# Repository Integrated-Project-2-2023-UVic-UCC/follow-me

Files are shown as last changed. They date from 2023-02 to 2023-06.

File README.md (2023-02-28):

# Follow-me robot

Follower robots are devices that use sensors to detect and track a person or object. These robots can be programmed to move in a specific direction and maintain a certain distance from what they are following. Such robots are used in various applications, such as surveillance, logistics, inspection, and support for people with mobility impairments. Thanks to their ability to follow and interact with their users, follower robots are gaining popularity in many fields.

Creating a robot that follows a person and carries boxes can be an exciting and useful project. The robot should be designed with sensors and algorithms that allow it to detect and track the person in real-time, while also being able to carry heavy objects such as boxes. This may require the integration of motors and acceleration mechanisms so that the robot can move efficiently, as well as advanced software that can interpret sensor data to control the robot's movement. With proper planning and the right tools, creating a robot that follows a person and carries boxes could be a highly rewarding task with great potential for practical applications.

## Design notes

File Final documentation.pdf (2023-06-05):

Technical document

# FOLLOW-ME ROBOT

Ferran Huéscar, Eloi Garcia, Jordi Rovira & Jana Bover

## Degree in Mechatronics Engineering

Subject: Integrated Project II

Vic, June of 2023

# Summary

Title:Follow-me robot
Authors: Ferran Huéscar, Eloi Garcia, Jordi Rovira i Jana Bover Subject: Integrated Projects II
Date: Vic, June of 2023
Keywords: Autonomously, Assistance, Sensors, Wireless

The main idea of this project is to create an advanced follow-me robot that can autonomously track and follow a person, providing uninterrupted assistance and support. With the ability to detect and follow individuals using sophisticated sensors, our robot adapts to their movements and pace without the need for constant manual control. This allows users to focus on their primary objectives while the robot autonomously accompanies them in their activities.

In addition to its core tracking capability, the robot will be equipped to carry objects, alleviating the burden on individuals and further optimizing tasks. Whether it's retrieving tools, transporting goods, or providing on-the-go assistance, our robot will be a valuable companion in various professional and personal settings.

Prioritizing convenience and practicality, our follow-me robot will operate wirelessly with a long-lasting battery. This freedom from cables and power outlets ensures maximum flexibility and mobility, enabling the robot to move and follow people in a wide range of environments, including offices, warehouses, and even outdoor spaces.

# Table of Contents

1. Introduction / State of the art – Benchmarking | 6
2. Objectives | 7
3. Development of the project | 9
3.1. Analysis of the problem and possible solutions. | 9
3.2. Description of the design. | 10
3.2.1. Mechanical design | 14
3.2.2. Electrical design. | 16
3.2.3. Control and software. | 18
3.3. Functional testing of the prototype | 19
4. Cost of the project | 20
5. Conclusions | 22
6. Bibliography | 24
7. Annexes | 26

# List of tables

# List of Figures

Figure 1 | First conceptual design of the follow-me robot | 9
Figure 2 | First 3D schematics of the robot with Sketchup | 10
Figure 3 | First 3D schematics of the robot with Sketchup | 11
Figure 4 | X-Ray view of the first 3D schematics | 11
Figure 5 | Render of the main view of the robot | 12
Figure 6 | Render of robot profile view | 13
Figure 7 | Render of robot front view | 13
Figure 8 | Electrical schematics for the connections design | 17

### 1. Introduction / State of the art – Benchmarking

Follower robots have emerged as versatile devices equipped with sensors to detect and track individuals or objects. These intelligent robots can be programmed to navigate specific paths while maintaining a constant distance from their target. Their applications span across diverse fields, including surveillance, logistics, inspection, and assisting people with limited mobility.

As follower robots continue to gain popularity due to their interactive capabilities, there arises an exciting opportunity to design a robot that not only tracks a person in real-time but also assists in carrying heavy objects like boxes. Achieving this requires a combination of cutting-edge sensors, algorithms, motors, acceleration mechanisms, and sophisticated software to interpret sensor data and control the robot's movements efficiently. By undertaking such a project with meticulous planning and the right tools, the creation of a person-following, box-carrying robot can yield substantial rewards and hold immense potential for practical applications.

### 2. Objectives

The main goal of our project is to create an advanced follower robot that can autonomously track and follow a person, providing seamless assistance and support.

But also there are specific objectives of this assignment:

1. Design and build a robot that can follow a person autonomously.
2. Integrate sensors to allow the robot to detect and follow a person.
3. Develop a control system to allow the robot to follow a person smoothly and smoothly.
4. Add additional functionality to the robot, such as the ability to carry objects.
5. Wireless robot using a battery.

Finally, in the management section we aim to structure, follow and organize the following tasks:

| | FEBRUARY | MARCH
TASKS | ASSIGN MENT | 1 4 | 1 5 | 1 6 | 1 7 | 1 8 | 1 9 | 2 0 | 2 1 | 2 2 | 2 3 | 2 4 | 2 5 | 2 6 | 2 7 | 2 8 | 1 | 2 | 3 | 4 | 5 | 6 | 7 | 8 | 9 | 1 0 | 1 1 | 1 2 | 1 3 | 1 4 | 1 5 | 1 6 | 1 7 | 1 8 | 1 9 | 2 0 | 2 1 | 2 2 | 2 3 | 2 4
Milestone 0 document | Group
First design | Ferran
Presentation milestone 0 | Group
Shopping list | Group
Navigation research | Jordi
Motors calculations | Eloi
Electronics research | Jana
Preliminary design | Ferran
Prototipe | Eloi
Hardware test | Jana
Final code | Jordi
Mid-term presentation | Group
Final design | Ferran
GitHub | Group

Table 1. Planning of tasks throughout the project

### 3. Development of the project

Once we discussed the project objectives and what we were willing to achieve, we began searching for possible solutions and subsequently creating initial sketches and diagrams. Below is a detailed explanation of all the solutions obtained and descriptions of the designs: the mechanical design, the electrical design, and all software control. Finally, we present the tests performed until achieving proper functioning.

3.1. Analysis of the problem and possible solutions.

The main problem we aimed to solve was to create a robot that could follow a person or object autonomously, using sensors and control algorithms. After conducting some research, we identified some possible solutions to achieve this goal, which included:

1. Ultrasonic Sensors that can detect obstacles and measure distances using ultrasonic waves. By using these sensors, the robot could follow a person or object without colliding with other obstacles.
2. Infrared Sensors that can detect heat signatures and can be used to detect humans or animals, which would allow the robot to follow a person or pet.
3. Vision-Based Sensors that can detect visual cues, such as colour or shapes, and could be used to track a person or object based on these visual cues.
4. GPS and Navigation so the robot could follow a person or object autonomously without the need for sensors. However, this solution would only work in outdoor environments where GPS signals are available.

After analyzing these solutions, we decided to use a LIDAR. The LIDAR sensors would be used to detect obstacles and p t collisions and to track a person or object.

Additionally, we decided to use two wheels behind to provide the robot with mobility and maneuverability. The robot’s dimensions were 200cm x 150cm, and it weights approximately 1.5kg. The robot is powered by a 12V DC motor and had a battery life of approximately 2 hours.

For the programming part, we used Python, which allow us to control de LIDAR. We also use Arduino to control the motors and other components of the robot.

Overall, the communication of the LIDAR, along with the two wheels drive system, allows to the robot to follow a person or object autonomously while avoiding obstacles.

3.2. Description of the design.

One of the key factors for the successful development of this robot has been the utilization of 3D printing as the primary manufacturing method. 3D printing is a technology that allows the creation of three-dimensional objects by layering materials, providing great versatility in terms of design and production. Thanks to this groundbreaking technique, we have been able to develop a robot with specific features and functionalities tailored for the transportation of small to medium-sized loads.

3D printing has also proven to be a highly efficient method in terms of costs and production times. By avoiding traditional manufacturing processes and associated expenses, we have been able to significantly accelerate the development of our robot, enabling rapid iterations in design and bringing the product to market more efficiently.

Firstly, taking into account the initial specifications, which include two drive wheels, two caster wheels, a platform for weight transportation, and the necessary capacity to accommodate all electronic components, we created the following preliminary layout.

Below is a development of the conceptual design of the robot.

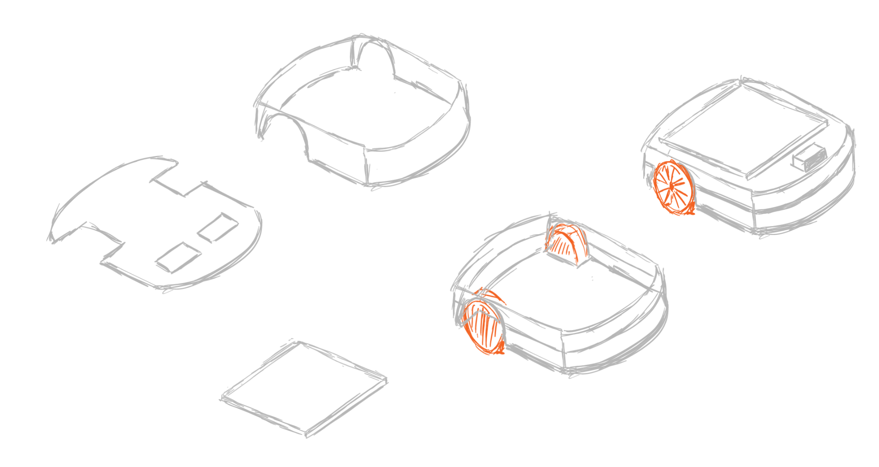
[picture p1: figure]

Fig 1. First conceptual design of the follow-me robot

Once the shape and aesthetics of the robot were determined, we decided to transfer it to the computer to begin deciding on the overall dimensions of the robot.

Therefore, we used the SketchUp program to create the first 3D schematic of our robot. Some changes were made to the second drawing, such as reducing the platform for weight loading since the LIDAR took up a significant portion of the upper platform of the robot. Additionally, we added a groove at the front of the robot. The resulting design is shown below:

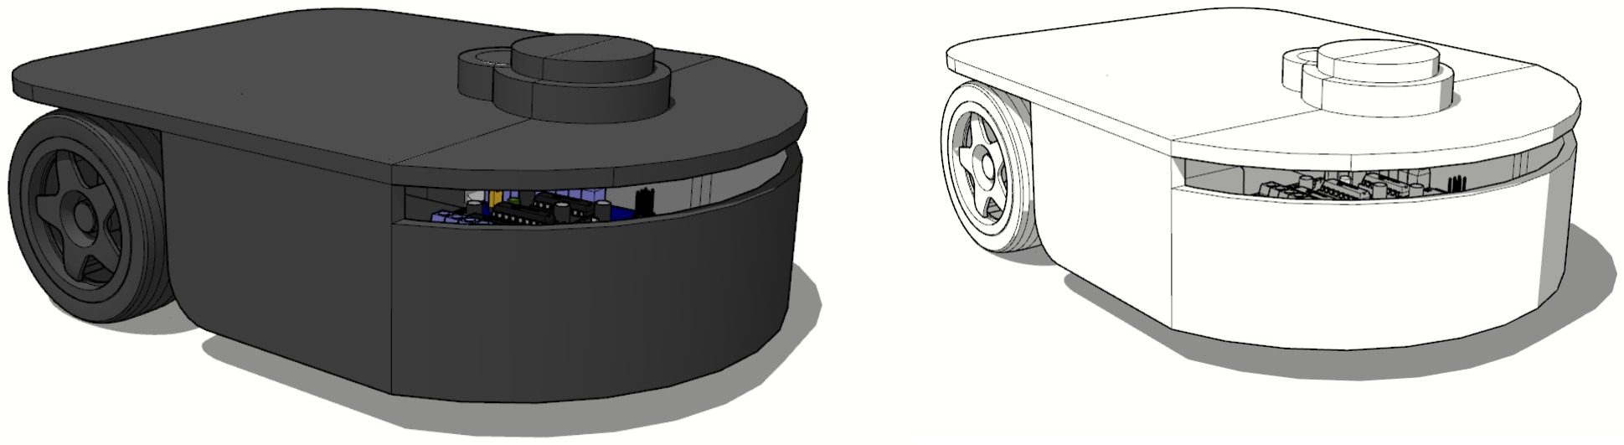
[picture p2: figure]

Fig 2&3. First 3D schematics of the robot with Sketchup

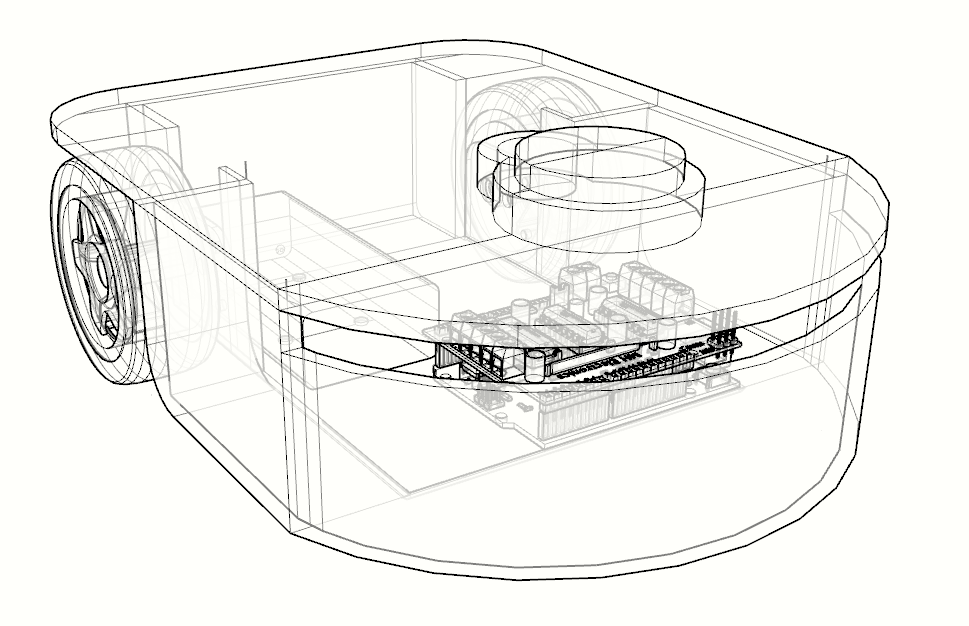
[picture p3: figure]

Fig 4. X-Ray view of the first 3D schematics

Finally, once we have determined the electronic components which motors go, the battery, the drivers, or the diameters of the wheels, we have been able to adapt the design based on the items purchased.

Some of the features that we have implemented in this latest design are supports for the lidar sensor, supports for the connection plate, joints between platforms, or holes to connect the battery externally.

To make the final result in 3D we have used the PTC Creo program since it is easy to use, versatile and all the members of the group can use it without accessibility problems. On the other hand, the final 2D plans have also been made with the same program, which has meant speed when generating them.

Below we show the final renders implemented with the PTC Creo program.

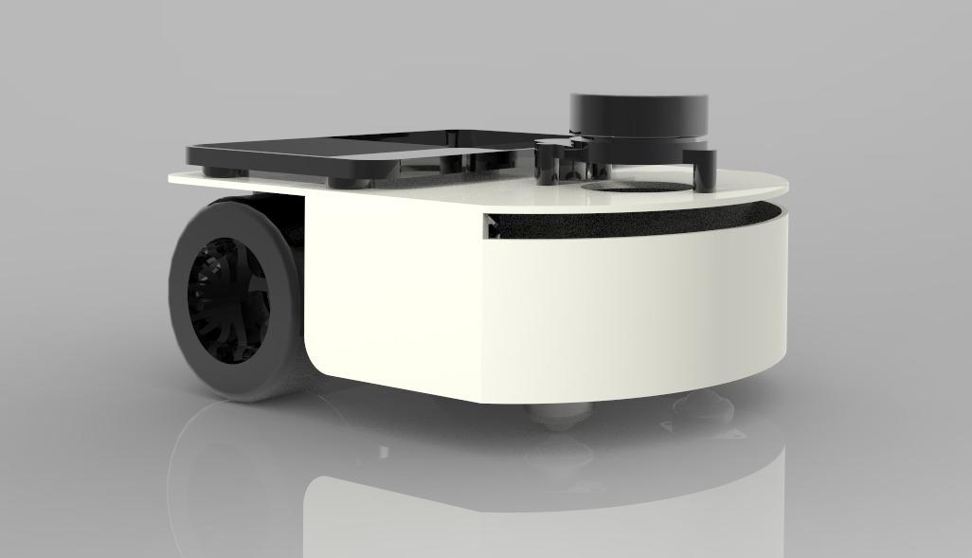
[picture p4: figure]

Fig 5. Render of the main view of the robot

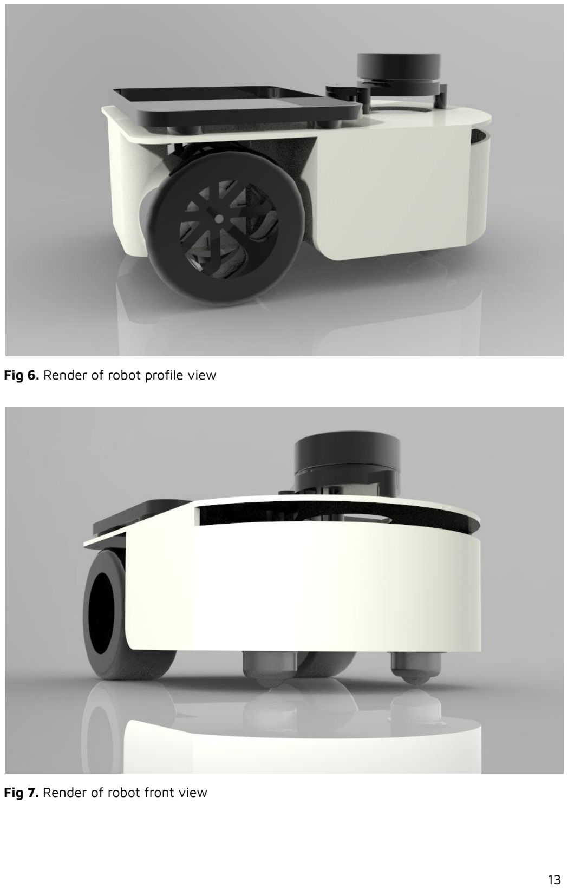
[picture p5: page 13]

Fig 6. Render of robot profile view

Fig 7. Render of robot front view

### 3.2.1. Mechanical design

In order to determine the mechanical specifications of the motors we studied all the factors included on the equation of making a follow-me robot run.

- Angular Velocity Calculation:

To determine the required angular velocity (ω) at which the motor shaft should rotate, we used the formula:

v = ω * R

where v is the desired linear velocity of the wheels and R is the radius of the wheels. Assuming the chosen wheels have a radius of approximately 35 mm, we can substitute this value into the formula to calculate the angular velocity.

- RPM Calculation:

To determine the minimum and maximum RPM (revolutions per minute) of the wheels, we need to convert the angular velocity from rad/s to RPM. The conversion formula is:

RPM = (ω * 60) / (2π)

By substituting the calculated angular velocity into this formula, we can find the RPM of the wheels. This information is useful for determining the specifications of the motors required.

- Motor Torque Calculation:

Motor torque is influenced by various factors, including the weight of the robot, the number of contact points touching the ground, and the friction of the surface. To calculate the total torque needed to start moving the robot from standstill for each wheel, we used the following formula:

Torque = (0.105 Nm * 4 wheels) / (2 driven)

This formula assumes that each wheel requires the same torque, and only two wheels are driven. By using this formula, we can determine the minimum torque that each motor should have.

- Power Calculation:

The power required by each wheel can be calculated using the following formula:

Power = (1.5 W * 4 wheels) / (2 driven)

This formula distributes the total power equally between the two driven wheels. By applying this formula, we can determine the minimum power rating that each motor should possess.

In summary, the motor calculations involve determining the angular velocity based on the wheel radius, calculating the RPM of the wheels, estimating the required torque based on the robot's weight, contact points, and friction, and finally, determining the minimum power rating for the motors. These calculations provide essential information for selecting the motors that are suitable for the given specifications and requirements of the robot.

3.2.2. Electrical design.

Below is the complete electrical schematic including the final PCB. It showcases all the research done for each component to ensure its proper functioning.

Our project includes an ESP32, two drivers to control the stepper motors, a LIDAR, a buck converter, and a battery supply involves several components and considerations.

The ESP32 is a popular microcontroller that can handle multiple tasks simultaneously and supports Wi-Fi and Bluetooth connectivity, It can be programmed using the Arduino IDE or other programming languages. In our project, to control the microcontroller we program it with Python.

The motor drivers are essential components for controlling the motors of the robot. They are responsible for providing the necessary power and control to the motors. There are various types of motor drivers available, such as H-bridge and L298N motor drivers. We use the DRV8825 driver.

LIDAR (Light Detection and Ranging) is a remote sensing technology that uses laser pulses to measure distance and create 3D maps of the environment. It can be used for obstacle avoidance and mapping of the surrounding area.

We also implement a buck converter, and it’s a DC-DC converter that steps down the voltage from the battery supply to a lower voltage that is suitable for the microcontroller and other components. It is essential for providing a stable and regulated voltage to the microcontroller and other components.

The battery supply is another essential component for powering the robot. It is important to choose the right type of battery that can provide enough power for the motors and other components and has sufficient capacity for the desired operating time.

When designing the electrical system, it is important to carefully consider the power requirements of each component and choose appropriate voltage regulators and other components to ensure that each component receives the correct voltage and current. Proper wiring and component selection are also crucial to prevent shorts or other electrical problems; That is why for the components that need 12V, we used a bigger wire.

In summary, after researching and understanding the datasheets of all the components, we carefully made the pcb with the proper wires and the proper components.

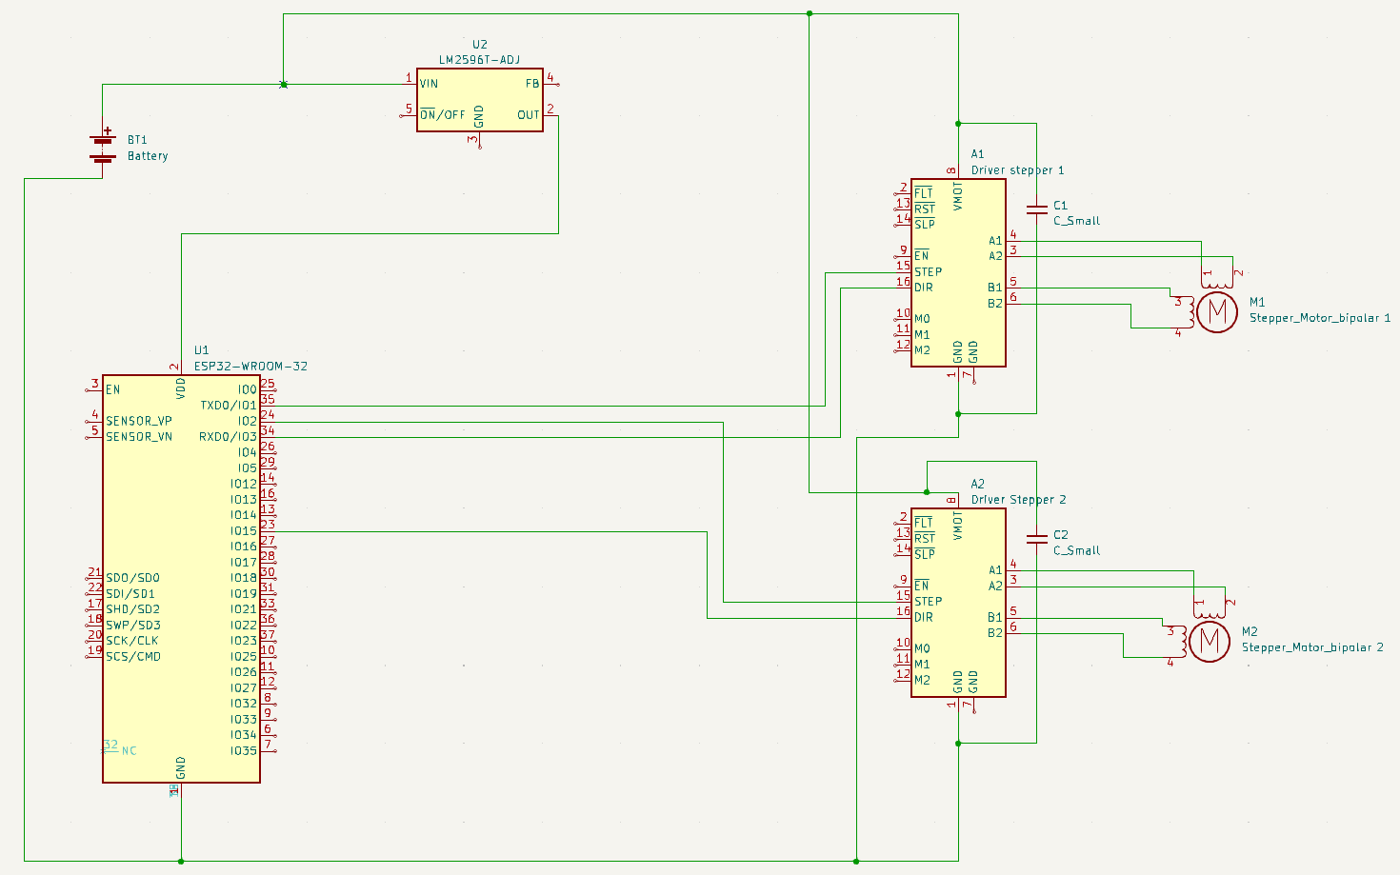
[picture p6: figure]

Fig 8. Electrical schematics for the connections design

3.2.3. Control and software.

The purpose of this section is to provide a comprehensive overview of the control and software aspects of a robotics project aimed at developing a robot that follows a user using a LiDAR sensor. The LiDAR data is decoded using Python, while the movement of the robot is controlled by two stepper motors, which are controlled via an Arduino microcontroller with an ESP32. This document will outline the system architecture, software components, and their functionalities.

- System Architecture

The control and software system for the LiDAR-based robot comprises the following components:

- LiDAR Sensor

Type: Triangulation lidar LD14P

The LiDAR sensor scans the environment and generates distance measurements, the raw data is sent to the Python program for decoding.

- Python Program

The program reads the raw byte stream from the LiDAR sensor and it decodes the byte stream according to the sensor's communication protocol and establishes a serial communication link with the Arduino microcontroller using the appropriate port.

It formats the decoded data and sends it as a serialized message via the serial connection. The decoded data represents distance measurements and angle to define a certain position from the LiDAR sensor.

Taking advantage of the possibilities offered by Python libraries, we utilize the decryption process to also display what the sensor sees.

Dependencies: pyserial, scipy, numpy, matplotlib

- Arduino with ESP32

The Arduino microcontroller, equipped with an ESP32 module, receives the serialized message from the Python program via the serial port and determines the appropriate movement commands based on the received data.

The program adjusts the motor movements to follow the nearest detected object.

### 3.3. Functional testing of the prototype

This section outlines the steps involved in functional testing and highlights any challenges or modifications encountered during the process.

Testing Procedure

- Data Decoding and Visualization

Initially, the LiDAR sensor data is decoded and visualized using Python and its libraries. The Python program reads the raw byte stream from the LiDAR sensor, decodes the data, and provides a graphical representation of the sensor readings. This step helps verify the proper functioning of the LiDAR sensor and the accuracy of the decoding process.

- Integration with ESP32 via Serial Communication

To streamline the control process and leverage the existing Python code, a decision was made to communicate the LiDAR sensor with the ESP32 microcontroller via the serial port from a computer. This required adapting an FTDI (USB-to-Serial) module to establish the serial communication between the computer and the LiDAR sensor.

- Challenges and Modifications

During the functional testing of the prototype, the following challenges were encountered:

- LiDAR Sensor Board Failure

In the initial stages of testing, the board that came with the LiDAR sensor suffered a failure. To continue with the project, an alternative solution was devised by adapting an FTDI module for serial communication. This modification enabled the team to proceed with the programming and testing of the robot.

- Limited Time for ESP32 Dual-Core Programming

Given the project timeline, it was not possible to fully utilize the dual-core capability of the ESP32 microcontroller. It was initially intended to program the microcontroller to operate with two loops simultaneously, utilizing the two cores for improved wheel movement during turns. Unfortunately, due to time constraints, this enhancement could not be implemented. However, it remains a potential improvement for future iterations of the project.

### 4. Cost of the project

Calculations of the costs of the project:

Below is a graph of the hours spent on the project based on the work sector. And the detail of the sections is:

- Mechanical: design, calculations, drawings, 3D printer, assembly, manufacturing processes, list of mechanical materials.
- Electrical: electronic design, electrical schematics, electronic components test, assembly, list of electronic materials.
- Programming: code, control system, software tests.
- Management: | meetings, | plannings, | milestones, | presentations, | final
documentation, video, GitHub, website.

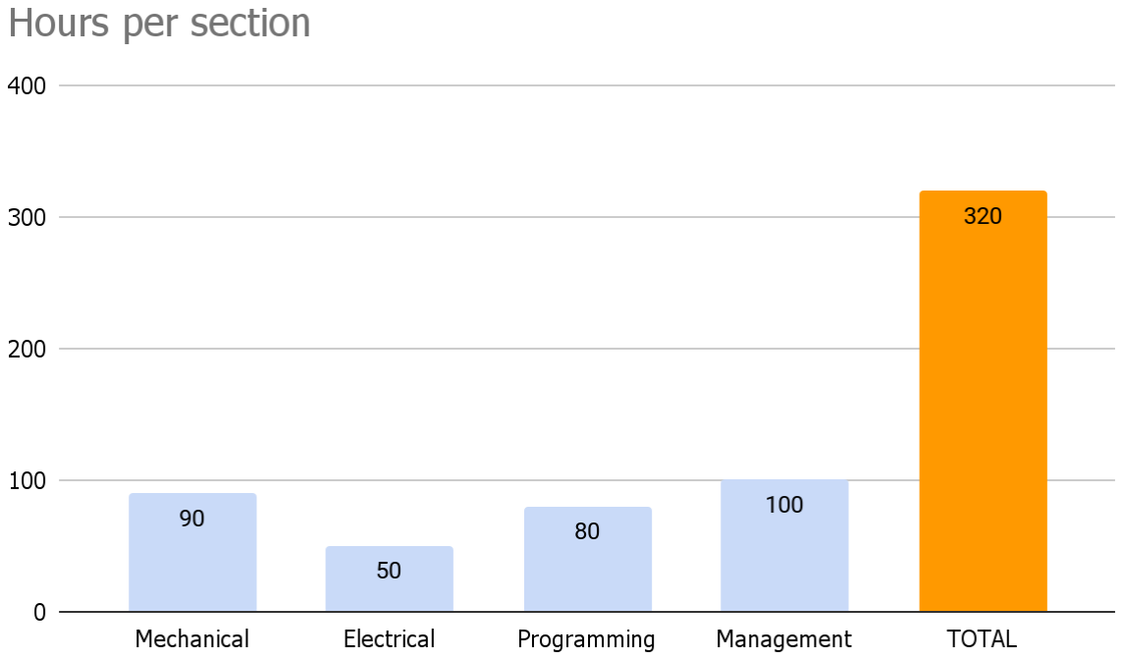
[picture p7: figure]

Table 3. Hours per section to calculate the final budget

On the other hand, the hours spent by each member of the group are difficult to define, even so we have distributed the work equally, therefore it is approximately 150 hours for each one.

Finally, to calculate the total budget of the project we have taken into account all the materials from the shopping list and the man-hours price given a standard engineer hour price.

Below is a table of all prices and the total budget:

Description | Quantity | Unit Price | Amount
Stepper motor | 2 | 20,99€ | 41,98€
ESP32 | 1 | 11,99€ | 11,99€
Pack 5 Converter | 1 | 10,99€ | 10,99€
Laser Lidar | 1 | 86,9€ | 86,9€
Pack 5 Drivers | 1 | 25,99€ | 25,99€
Pack 2 free wheels | 1 | 8€ | 8€
Pack 2 Wheels | 1 | 21,79€ | 21,79€
Battery | 1 | 23,5€ | 23,5€
Battery connector | 1 | 3,99€ | 3,99€
Bolts (M3x8mm ) | 10 | 0€ | 0€
Bolts (D2.2x1cm ) | 4 | 0€ | 0€
SUBTOTAL | | | 265,38€
Mechanical hours | 90 | 15€ | 1350€
Electrical hours | 50 | 15€ | 750€
Programming hours | 80 | 15€ | 1200€
Management hours | 100 | 15€ | 1500€
SUBTOTAL | | | 4800€
TOTAL | | | 5065,38€

Table 2. Table of all prices and the total budget of the project

### 5. Conclusions

In conclusion, the project aims to create an advanced follower robot that can autonomously track and follow a person, while also having the ability to carry objects. The project involves several components, including mechanical design, electrical design, control and software development.

The mechanical design utilizes 3D printing to create the robot, allowing for customization and rapid iterations in design. And the electrical design includes components such as an ESP32 microcontroller, motor drivers, LIDAR sensor, buck converter, and battery supply.

The control and software development involve programming the ESP32 with Python, decoding the data from the LIDAR sensor, and controlling the robot's movement based on the received data.

The project follows a structured development process with tasks planned and assigned to team members.It also includes cost analysis, with tables indicating the budget and hours allocated for each section. Functional testing of the prototype is conducted to ensure proper functioning and address any challenges or modifications.

Overall, the project demonstrates a comprehensive approach to designing and developing a follower robot with advanced capabilities. The combination of mechanical design, electrical components, and software control showcases a systematic and well-structured approach to achieving the project's objectives.

### 6. Bibliography

Bibliography must be numbered. All bibliography entries must be cited in the main text of the document.

1. Website link of Stepper motors:

https://www.amazon.es/Creality-Stepper-Impresora-Grados-Ender-3/dp/B091D37BM2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 (https://www.amazon.es/Creality-Stepper-Impresora-Grados-Ender-3/dp/B091D37BM2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)

2. Website link of ESP32:

https://www.amazon.es/HiLetgo-ESP-wroom-32-Desarrollo-procesador-microcontrolador/dp/B0718T232Z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 (https://www.amazon.es/HiLetgo-ESP-wroom-32-Desarrollo-procesador-microcontrolador/dp/B0718T232Z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)

3. Website link of Converter:

https://www.amazon.es/Yizhet-Convertidor-Regulador-Ajustable-Alimentaci%C3%B3n/dp/B0823P6PW6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 (https://www.amazon.es/Yizhet-Convertidor-Regulador-Ajustable-Alimentaci%C3%B3n/dp/B0823P6PW6)

4. Website link of Laser Lidar:

https://botland.store/laser-scanners-lidar/22016-lidar-ld14-360-degree-laser-scanner-8m-range-waveshare-22415.html (https://botland.store/laser-scanners-lidar/22016-lidar-ld14-360-degree-laser-scanner-8m-range-waveshare-22415.html)

5. Website link of Drivers

https://www.amazon.es/WJMY-Controlador-Stepper-Disipador-Machines/dp/B08R64Y7V7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 (https://www.amazon.es/WJMY-Controlador-Stepper-Disipador-Machines/dp/B08R64Y7V7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)

6. Website link of Free wheels

https://fadisel.com/ca/roda-boja-o-roda-robotica/1055-roda-boja-acer-o-25-mm.html

7. Website link of Motor wheels https://www.amazon.es/Dilwe-Neum%C3%A1ticos-Coche-Rueda-Pl%C3%A1stico/dp/B07DZS4T6J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 (https://www.amazon.es/Dilwe-Neum%C3%A1ticos-Coche-Rueda-Pl%C3%A1stico/dp/B07DZS4T6J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)
8. Website link of Battery

https://www.amazon.es/OVONIC-bater%C3%ADa-Paquetes-2200mAh-Evader/dp/B07LFS8ZL6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 (https://www.amazon.es/OVONIC-bater%C3%ADa-Paquetes-2200mAh-Evader/dp/B07LFS8ZL6)

9. Website link of Battery connector

https://www.amazon.es/Conectores-bater%C3%ADa-Battery-Vehicle-Hembra/dp/B074RGT76J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 (https://www.amazon.es/Conectores-bater%C3%ADa-Battery-Vehicle-Hembra/dp/B074RGT76J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)

10. Instructables web

https://www.instructables.com/Follow-Me-Robot/

### 7. Annexes

### 2D PTC CREO drawings

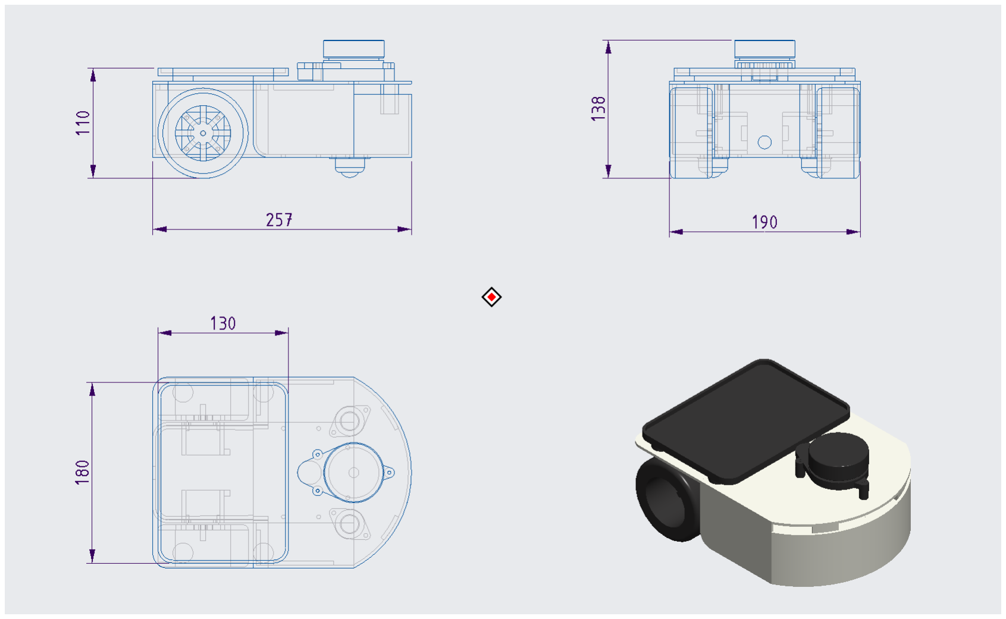
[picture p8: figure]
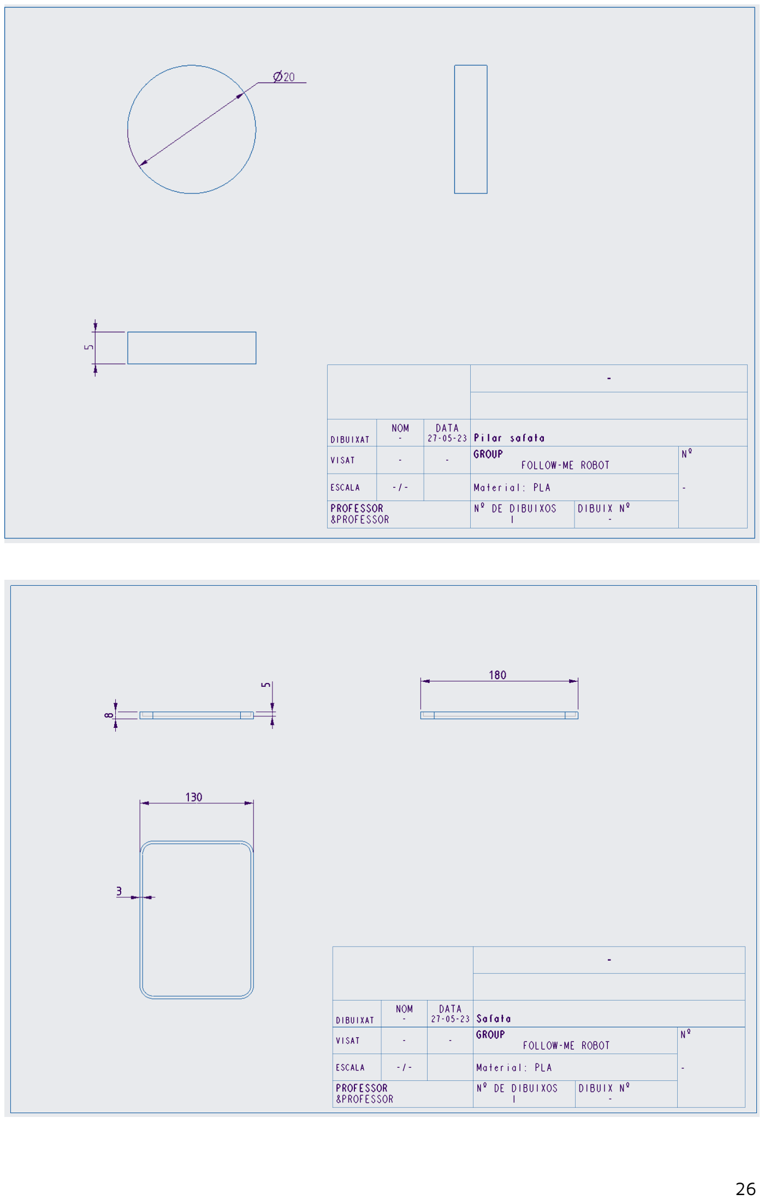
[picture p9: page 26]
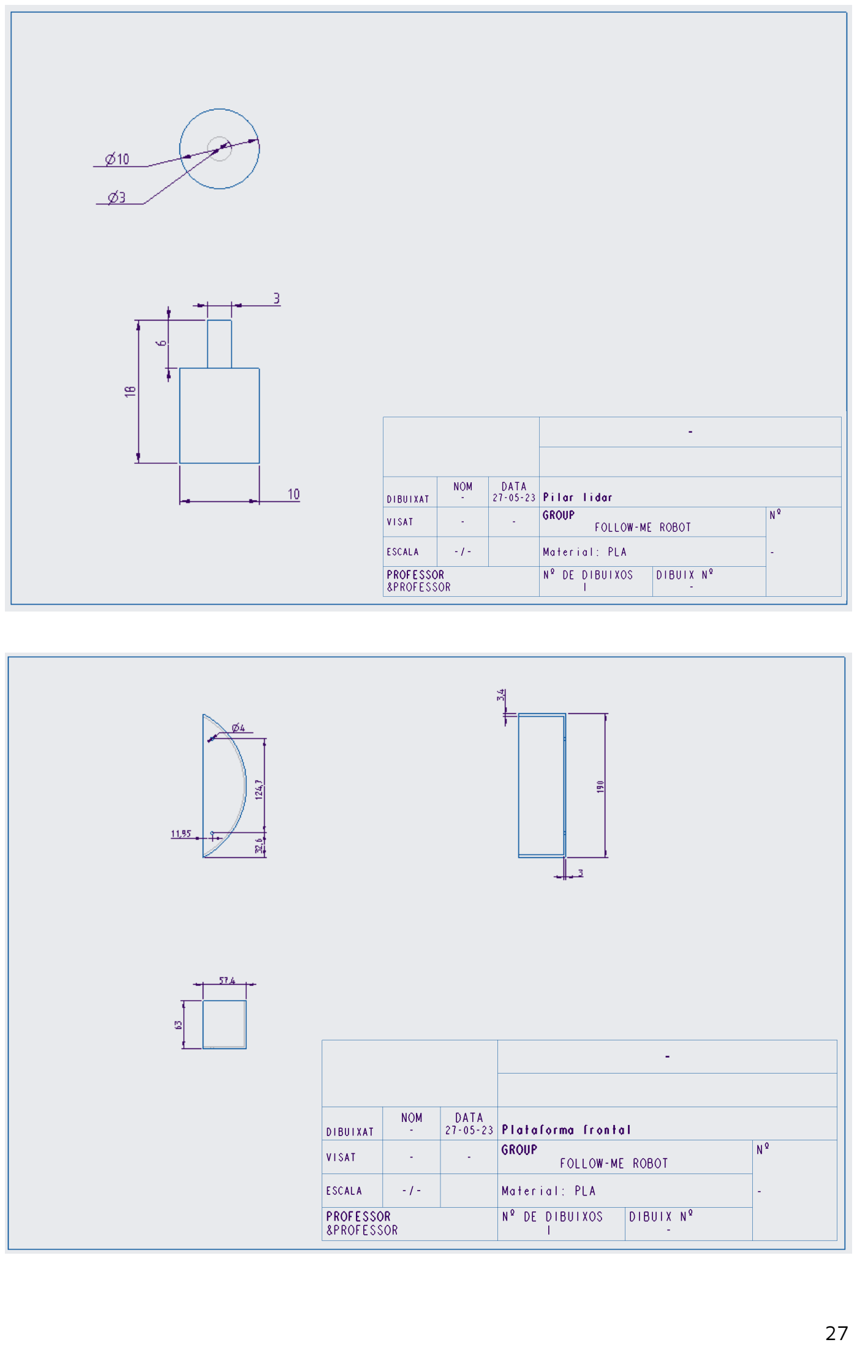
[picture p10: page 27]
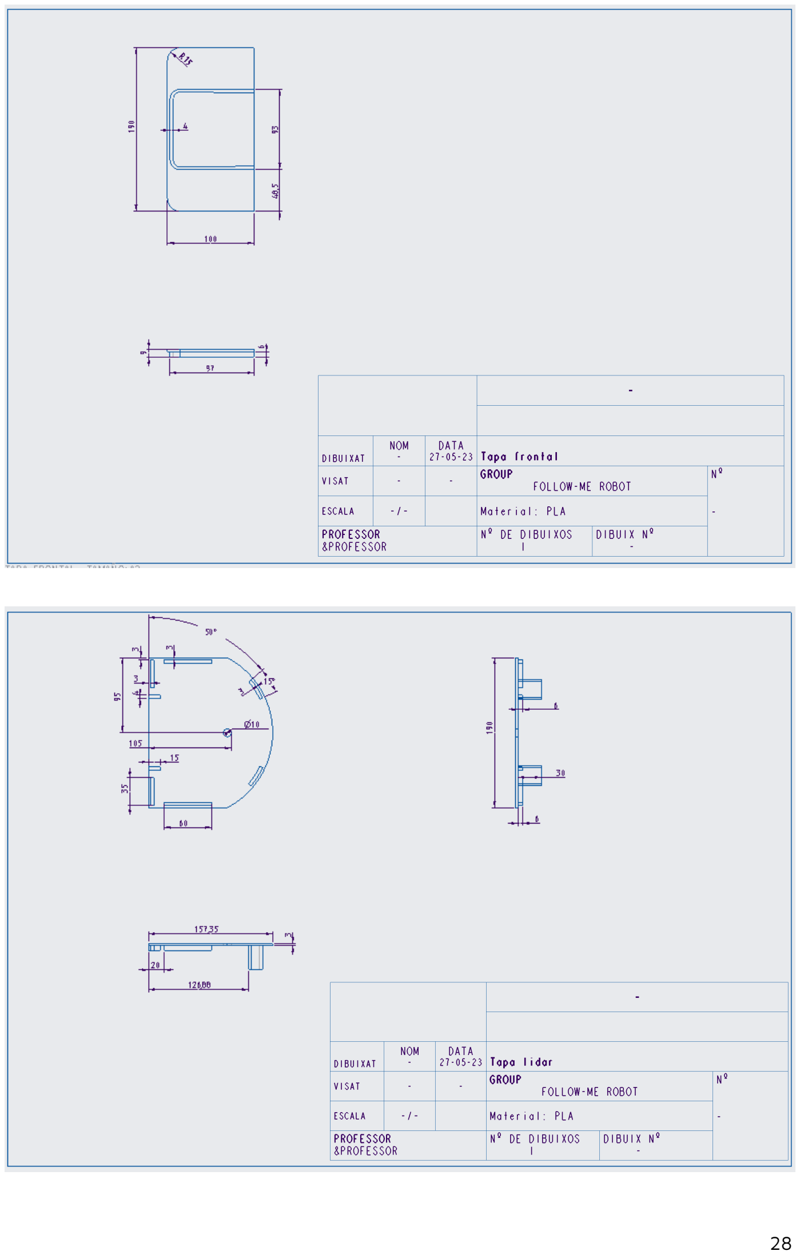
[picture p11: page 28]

### Python program

from pylab import *
import serial, time

ion()

com = 'COM7'

class DataFrame:#With this class I decode the LiDAR info

def __init__(self, verlen, speed, start_angle,points, end_angle, crc):
self.verlen = verlen #Value set to 0x2C(1Byte) packet type (I don't use it)
self.speed = speed #Rotation speed (2Byte)
self.start_angle = start_angle #Start angle of the data packet (2Bytes) 0.01degree self.end_angle = end_angle #Angle of the end of the data packet (2Bytes) 0.01degree self.points = points #DATA (3Bytes)
self.crc = crc #crc (I don't use it)

#int.from_bytes: Create an integer from bytes

@classmethod
def from_bytes(cls,buffer):#Here I create the data buffer
verlen = buffer[0] #I don't use it
speed = int.from_bytes(buffer[1:3], byteorder='little') #Speed (2Byte 2nd and 3rd) start_angle = int.from_bytes(buffer[3:5], byteorder='little')*0.01 #Start angle (2Byte 3rd and 4rd)
i = 5 #I do this to index the values in the buffer skipping the previous ones
points = [] #Here I add the distance and intensity values
for x in range(12):
dist = int.from_bytes(buffer[i:i+2], byteorder='little') #2 bytes of distance (5th and 6th) i += 2
intensity = int.from_bytes(buffer[i:i+1], byteorder='little') #1 Byte of intensity (7th)
i += 1
points.append((dist,intensity)) #I add them to the 'points' list

end_angle = int.from_bytes(buffer[i:i+2], byteorder='little')*0.01 #Final angle (8th) i += 1

crc = int.from_bytes(buffer[i:i+1], byteorder='little') #I don't use it

return cls(verlen, speed, start_angle, points, end_angle, crc)

dt = 35 # +- dt (angle)

def process_data(tt,dd): #This function restricts the range of angles

#return array([0]),array([0])

i = logical_and(tt>(180-dt),tt<(180+dt)) #The range of angles is from 145º to 215º

tt = tt[i] #theta
dd = dd[i] #distance

i = nonzero(dd) #Filter to remove errors (value 0) tt = tt[i] #theta
dd = dd[i] #distance

if tt.size<10:
return tt,dd #Filter if I have removed most items

i = argsort(dd) #Sort the values from smallest to largest tt = tt[i] #theta
dd = dd[i] #distance

N = 6
ttav = sum(tt[:N])/N
ddav= sum(dd[:N])/N

#Calculate the byte buffer of the message buff = int(ttav*100).to_bytes(2,"little") buff += int(ddav).to_bytes(2,"little") arduino.write(buff)

arduino.flush()

#print ('angle ',ttav,'distancia ', ddav)

return tt[:N],dd[:N]

#Read the serial port of the LiDAR ser = serial.Serial(com,

baudrate=115200,
parity=serial.PARITY_NONE, stopbits=1,
bytesize=8,
xonxoff=0, rtscts=0)

#Serial port of the esp32

arduino = serial.Serial("COM6", 115200)

time.sleep(2)

fig = figure() #Graph the position (This part is for the tests) ax = fig.add_subplot(111)

tt = array([], dtype=float)
dd = array([], dtype=float)
xx = array([0])
yy = array([0])

line, = ax.plot(xx,yy,'k.', markersize=1)
line_data, = ax.plot(xx,yy,'r.', markersize=5) ax.plot([-4000*cos(dt*pi/180),0,-4000*cos(-dt*pi/180)],[-4000*sin(dt*pi/180),0,-4000*sin(-dt*pi /180)])
ax.set_xlim(-4000,4000)

ax.set_ylim(-4000,4000)

while True:

nbytes = arduino.inWaiting()#read arduino serial port if nbytes:#if there is something follow
txt = arduino.read(nbytes) print(txt)#.decode("ascii"), end='') #Decodific ascii

# wait for start of frame (x54)

b = ser.read(1) #Read LiDAR serial port (1 byte)
if b!= b'\x54':
continue

# read frame

buffer = ser.read(46) #46 which is the length of the message

# decode frame.

frame = DataFrame.from_bytes(buffer) #the buffer is the 46 bytes of the message

if frame.end_angle < frame.start_angle: #Here it corrects the error caused when a string of values passes through 0º
frame.end_angle += 360

theta = linspace(frame.start_angle, frame.end_angle, 12)#12 points in each dataframe (creates a vector of angles)
pts = array(frame.points, dtype=float)
dist = pts[:,0]

# Concatenate data making sure we don't loose the information # about when new scan starts.

if tt.size>0 and tt[-1]>theta[0]:
theta += 360
tt = concatenate((tt,theta))
dd = concatenate((dd,dist))

# check if full scan acquired. if tt[-1] >= 360:

i = tt<360
fulltt = tt[i]
fulldd = dd[i]

i = tt>=360
tt = tt[i]-360
dd = dd[i]

# process tt and dd in range +-35degrees from 180

ptt,pdd = process_data(fulltt,fulldd)

xx = fulldd*cos(-fulltt*pi/180)
yy = fulldd*sin(-fulltt*pi/180)
line.set_xdata(xx)
line.set_ydata(yy)

xx = pdd*cos(-ptt*pi/180)

yy = pdd*sin(-ptt*pi/180)
line_data.set_xdata(xx)
line_data.set_ydata(yy)

fig.canvas.draw()
fig.canvas.flush_events()

### Arduino program

const int BUFFER_SIZE = 4; //for the received data char buf[BUFFER_SIZE];

const int DIR_MOTOR1 = 5; //pins for the stepper motors const int STEP_MOTOR1 = 18;
const int DIR_MOTOR2 = 0;
const int STEP_MOTOR2 = 4;

unsigned int dist; //received data distance

float theta; //received data angle

int pulse1 = 0; //that variable is to control the amount of steps each motor do on a turn

unsigned long previousMillis1 = 0; //will store last time
unsigned long currentMillis1 = 0; //will store current time

unsigned long previousMillis2 = 0; //will store last time
unsigned long currentMillis2 = 0; //will store current time

void setup() {
Serial.begin(115200);
Serial.setTimeout(10);
//Motor 1
pinMode(STEP_MOTOR1, OUTPUT); //step motor1 and his direction pinMode(DIR_MOTOR1, OUTPUT);

//Motor 2
pinMode(STEP_MOTOR2, OUTPUT);//step motor2 and his direction pinMode(DIR_MOTOR2, OUTPUT);

digitalWrite(DIR_MOTOR1, HIGH);
digitalWrite(DIR_MOTOR2, LOW);
}

unsigned long stepper_time = 0; //unsigned long stepper_time1 = 0; //unsigned long stepper_time2 = 0; float stepper_freq = 0;
//float stepper_freq_1 =0;
//float stepper_freq_2 =0;

void loop() {

if (Serial.available() > 0) {

int rlen = Serial.readBytes(buf, BUFFER_SIZE); //read bytes from serial port if (rlen != BUFFER_SIZE) {
return;
}

// prints the received data
//Serial.print("I received: ");
int th = buf[0] + (buf[1] << 8); //0 - 1 for distance dist = buf[2] + (buf[3] << 8); // 2 - 3 for angle

theta = ((float)th) / 100; //scale the angle units

//Serial.print(dist);
}

long set_pt = 0; //that's for the proportional speed - distance long err = dist - set_pt;
if (err < 0) {
stepper_freq = 0;
} else if (err > 2000) {
stepper_freq = 0;
} else {
stepper_freq = (float)err / 2000000.0;
}

stepper_freq = stepper_freq < 0.3e-3 ? 0 : stepper_freq; // below 0.3e-3 stepper_freq = 0 stepper_freq = stepper_freq > 0.7e-3 ? 0.7e-3 : stepper_freq; //over 0.7e-3 stepper freq = 0.7e-3

stepper_time = 1.0 / stepper_freq;

if (stepper_freq > 0.0) {

//Here are the motor controls,
//it can be seen that there is an offset, so the center of the sensor is not 180º, //and thats why the left and right turns are 4 degrees out of 180º +- 10º

if (theta < 179.0) { //turn left

currentMillis1 = micros();
if (currentMillis1 - previousMillis1 >= stepper_time) { digitalWrite(STEP_MOTOR2, HIGH);
pulse1 += 1;//to do the turn i restrict the half of the steps from one motor if (pulse1 >= 2) {
digitalWrite(STEP_MOTOR1, HIGH);
}
previousMillis1 = currentMillis1;
}

currentMillis2 = micros();
if (currentMillis2 - previousMillis2 >= stepper_time*2) { digitalWrite(STEP_MOTOR2, LOW);
if (pulse1 >= 3) {
digitalWrite(STEP_MOTOR1, LOW);

pulse1 = 0;
}
previousMillis2 = currentMillis2;

}
}

else if (theta > 189.0) { //turn right
currentMillis1 = micros();
if (currentMillis1 - previousMillis1 >= stepper_time) { digitalWrite(STEP_MOTOR1, HIGH);
pulse1 += 1;//to do the turn i restrict the half of the steps from one motor if (pulse1 >= 2) {
digitalWrite(STEP_MOTOR2, HIGH);
}
previousMillis1 = currentMillis1;
}

currentMillis2 = micros();
if (currentMillis2 - previousMillis2 >= stepper_time*2) { digitalWrite(STEP_MOTOR1, LOW);
if (pulse1 >= 3) {
digitalWrite(STEP_MOTOR2, LOW);
pulse1 = 0;
}
previousMillis2 = currentMillis2;

}
}

else { //go straight
currentMillis1 = micros();
if (currentMillis1 - previousMillis1 >= stepper_time) { digitalWrite(STEP_MOTOR1, HIGH); digitalWrite(STEP_MOTOR2, HIGH); previousMillis1 = currentMillis1;
}

currentMillis2 = micros();
if (currentMillis2 - previousMillis2 >= stepper_time*2) { digitalWrite(STEP_MOTOR1, LOW); digitalWrite(STEP_MOTOR2, LOW); previousMillis2 = currentMillis2;
}
}

//digitalWrite(STEP_MOTOR1, HIGH); //digitalWrite(STEP_MOTOR2, HIGH); //delayMicroseconds(stepper_time);

//digitalWrite(STEP_MOTOR1, LOW); //digitalWrite(STEP_MOTOR2, LOW); //delayMicroseconds(stepper_time); }
}

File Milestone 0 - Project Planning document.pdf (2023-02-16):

# MILESTONE 0: FOLLOW-ME ROBOT

Jordi Rovira, Eloi Garcia, Ferran Huéscar, Jana Bover

### 0.1 Introduction

Follower robots are devices that use sensors to detect and track a person or object. These robots can be programmed to move in a specific direction and maintain a certain distance from what they are following. Such robots are used in various applications, such as surveillance, logistics, inspection, and support for people with mobility impairments. Thanks to their ability to follow and interact with their users, follower robots are gaining popularity in many fields.

Creating a robot that follows a person and carries boxes can be an exciting and useful project. The robot should be designed with sensors and algorithms that allow it to detect and track the person in real-time, while also being able to carry heavy objects such as boxes. This may require the integration of motors and acceleration mechanisms so that the robot can move efficiently, as well as advanced software that can interpret sensor data to control the robot's movement. With proper planning and the right tools, creating a robot that follows a person and carries boxes could be a highly rewarding task with great potential for practical applications.

### 0.2 Main Objective

1. Create a follow-me robot in order to increasing efficiency and productivity.

### 0.3 Specific Objectives

This are the specific objectives of this project:

1. Design and build a robot that can follow a person autonomously.
2. Integrate sensors to allow the robot to detect and follow a person.
3. Develop a control system to allow the robot to follow a person smoothly and smoothly.
4. Add additional functionality to the robot, such as the ability to carry objects.
5. Wireless robot using a battery.

### 0.4 Team Organization

Regarding the organization and the separation of responsibilities of the group, the structure is as follows:

- Project manager: Jana Bover
- Mechanical leader: Eloi Garcia
- Electronics leader: Ferran Huéscar
- Software leader: Jordi Rovira

However, we will all get involved in all areas for a better rapport and understanding of the final result.

### 0.5 Tasks

On the other hand, after digressing and doing a little search on the internet we have initially decided on the following tasks:

1. Design: Outline the design of the robot, including its physical features, sensors, and software capabilities.
2. Functionality: Describe the robot's intended functionality, such as its ability to navigate the warehouse, identify and retrieve items, and transport goods to specified locations.
3. Implementation: Detail the steps necessary to build and deploy the robot, including any required hardware and software, as well as testing and validation procedures.
4. Potential benefits: Highlight the potential benefits of using the robot, such as reducing labor costs, improving accuracy, and increasing throughput.
5. Cost analysis: Estimate the cost of building and deploying the robot, as well as any ongoing maintenance and operational expenses.
6. Risks and challenges: Identify potential risks and challenges associated with the project, such as technical difficulties or regulatory compliance issues, and propose strategies for addressing them.
7. Future enhancements: Discuss possible future enhancements and developments for the robot, such as adding new capabilities or integrating with other systems.
8. Conclusion: Summarize the key points of the project and emphasize its potential impact on the warehouse operations

### 0.6 GitHub

In addition to the tasks proposed above, we will have to reflect and monitor the project with the GitHub tool. A platform for version control and collaboration on software projects. In this way, it will be important to transfer the day-to-day tasks, as well as the partial results of the project. In other words, we will be able to organize the work of all the members of the group, for better monitoring and progress of the project. On the other hand, it will also be easier to manage feedback from tutors.

### 0.7 Webpage address

Finally, once the project is finished, it will have to be captured on a web page called “instrucables.com”. This resource allows users to share and discover DIY projects (do it yourself). The platform hosts a wide variety of projects in categories like electronics, gardening, crafts, and more. Each project includes detailed step-by-step instructions, images, and materials needed to complete the project. Additionally, users can comment, ask, and share feedback on projects.

For our part, we are also going to include a promotional video of maximum two minutes. Our initial idea is to explain the general operation of the drone, show the final design, either through 3D renders or with the prototype already built, and film the drone's flight.

In short, this project is an exciting opportunity to learn and develop valuable skills. We are excited to work together on this project and see what results we get.

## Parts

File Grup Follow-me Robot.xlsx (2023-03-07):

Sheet: Project Specifications
TECHNICAL SPECIFICATIONS
Customer Company | Universitat de Vic - Universitat Central de Catalunya
Engineering Company | Follow-me Robot Group
Revision 1 | Date: 28/02/2023
List the main characteristics of the desired device
Item number | Description
1 | Move in any direction with the most narrow movements
2 | Carry load up to 2.5 kg
3 | Achieve Radio Control movements (step 1)
4 | Achieve autonomous movement (step 2)
5
Mechanical part
Dimensions (volume) | 250 mm x 350 mm x 100 mm (height)
Weight | 4 kg (including payload)
Wheels | 2 wheels 700 mm diameter and 2 freewheels
Materials for the mechanical part / structure | PVC plastic platform (250 x 350 x 3 mm), 3D printed parts, commercial omnidirectional wheels
Motors | Motor Stepper 0.9º , 140rpm, Torque = 0.250 Nm
Degrees of freedom | 4
Manufacturing equipment | 3D Printer, CNC Milling maching for PVC plastic platform
Assembly between parts | Bolts and nuts, welding for electrical and electronics parts
Electronic & programming part
Microcontroller | 1 Arduino UNO
Drivers | L298N Dual H-Bridge Stepper Motor Driver Board For Arduino
Sensors | Lider sensor
Communication | Noun
Programming | Arduino IDE, App Inventor
Power | 12V 1600mAh Rechargeable NiMh Battery
Autonomy | 25 min
Protoboard | No

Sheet: Conceptual_Design
CONCEPTUAL DESIGN
Include an image (or more than one) with the current status of the conceptual design. Can be a sketches done with pencil

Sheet: Shopping list
PRELIMINAR ORDER LIST
Team: | Follow-me Robot |  | Total cost [€] | 243.595
 |  |  | Budget limit [€] | 300
*nota: la bateria i el connector de bateria es la mateixa del grup del Domino
Item number | Description of the material | Quantity | Price [€] | Cost [€] | Provider | Link / website
1 | Stepper motor, stall Torque=0,4 Nm, 12 V | 2 | 20.99 | 41.98 |  | https://www.amazon.es/Creality-Stepper-Impresora-Grados-Ender-3/dp/B091D37BM2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
2 | esp32 | 1 | 11.99 | 11.99 |  | https://www.amazon.es/HiLetgo-ESP-wroom-32-Desarrollo-procesador-microcontrolador/dp/B0718T232Z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
3 | convertidor (van 5 unitats) | 1 | 10.99 | 10.99 |  | https://www.amazon.es/Yizhet-Convertidor-Regulador-Ajustable-Alimentaci%C3%B3n/dp/B0823P6PW6
4 | laser lider | 1 | 86.9 | 86.9 |  | https://botland.store/laser-scanners-lidar/22016-lidar-ld14-360-degree-laser-scanner-8m-range-waveshare-22415.html
5 | Drivers (van 5 unitats) | 1 | 25.99 | 25.99 |  | https://www.amazon.es/WJMY-Controlador-Stepper-Disipador-Machines/dp/B08R64Y7V7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
6 | Roda Boja (van 2 unitats) | 1 | 8.25 | 8.25 |  | https://fadisel.com/ca/roda-boja-o-roda-robotica/1055-roda-boja-acer-o-25-mm.html
7 | impresio 3D (inclou rodes) | 1 | 30 | 30
8 | bateria (*nota promoció 2x1) | 1 | 23.5 | 23.5 |  | https://www.amazon.es/OVONIC-bater%C3%ADa-Paquetes-2200mAh-Evader/dp/B07LFS8ZL6
9 | connector bateria | 1 | 3.995 | 3.995 |  | https://www.amazon.es/Conectores-bater%C3%ADa-Battery-Vehicle-Hembra/dp/B074RGT76J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
10 |  |  |  | 0
11 |  |  |  | 0
12 |  |  |  | 0
13 |  |  |  | 0
14 |  |  |  | 0
15 |  |  |  | 0
16 |  |  |  | 0
17 |  |  |  | 0
18 |  |  |  | 0
19 |  |  |  | 0
20 |  |  |  | 0
21 |  |  |  | 0
22 |  |  |  | 0

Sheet: Recommended suppliers
Provider | Description | link
RS Online | distributor of electronics, electricity and industrial maintenance products | https://es.rs-online.com/
BCN 3D Technologies | 3D Printing Filament distributor for our 3D printer BCN 3D Sigma | https://www.bcn3dtechnologies.com/ca/
Robotshop | Stepper motor, grippers, servo motors, arduinos, raspberry Pi, drivers for motors | https://www.robotshop.com/
Motedis | Mechanical components, aluminium profiles | https://www.motedis.es/shop/index.php
Amazon | Electronics and more | https://www.amazon.es/
ALACER MAS | Mechanical components, aluminium profiles | http://www.alacermas.com/index.php
Please check also the list of recommended providers in the virtual campus.
https://campus.uvic.cat/aules/pluginfile.php/830007/mod_resource/content/2/IP2_List_of_possible_providers.pdf

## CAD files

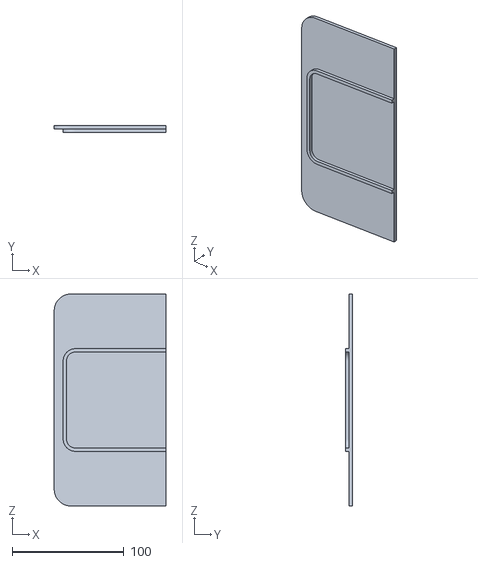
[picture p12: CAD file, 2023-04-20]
tapa_frontal_1.stl
100.0 x 6.00 x 190.0

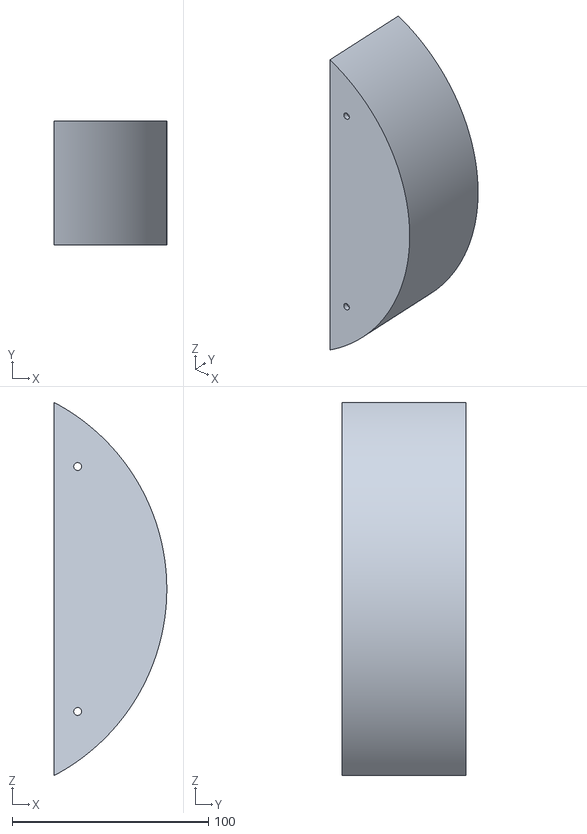
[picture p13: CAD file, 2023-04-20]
plataforma_frontal_1.stl
57.4 x 63.0 x 190.0

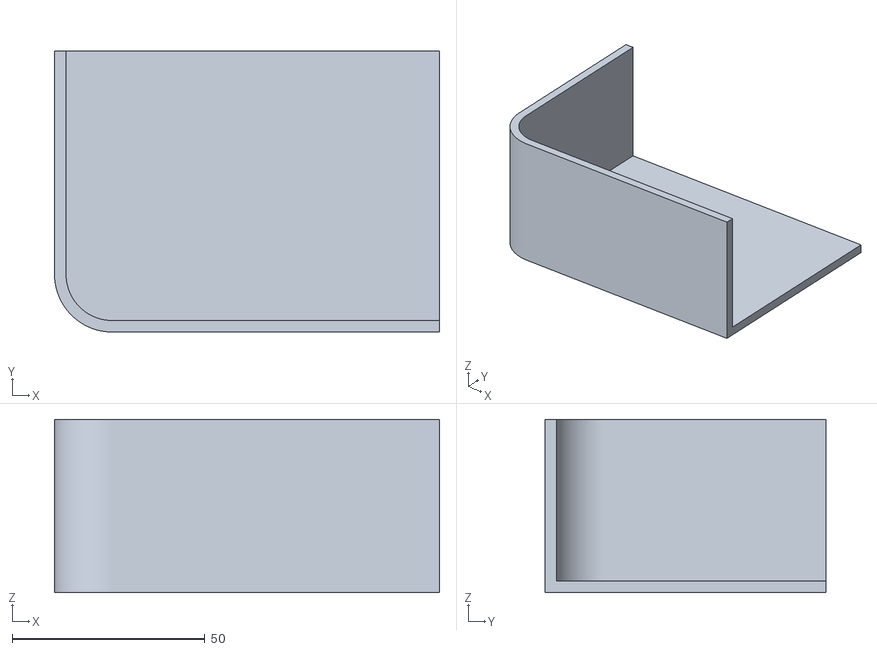
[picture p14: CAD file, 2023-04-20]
plataforma_Llateral_1.stl
100.0 x 73.0 x 45.0

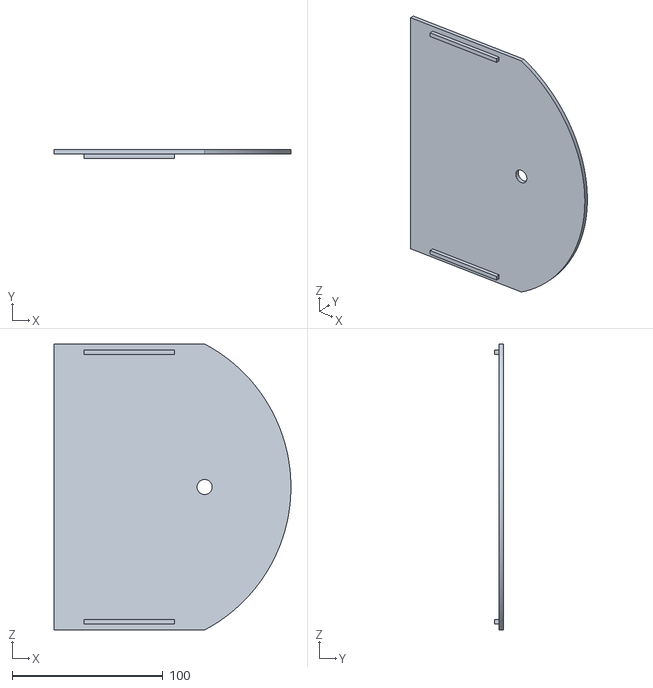
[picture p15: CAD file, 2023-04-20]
tapa_lidar_1.stl
157.4 x 6.00 x 190.0

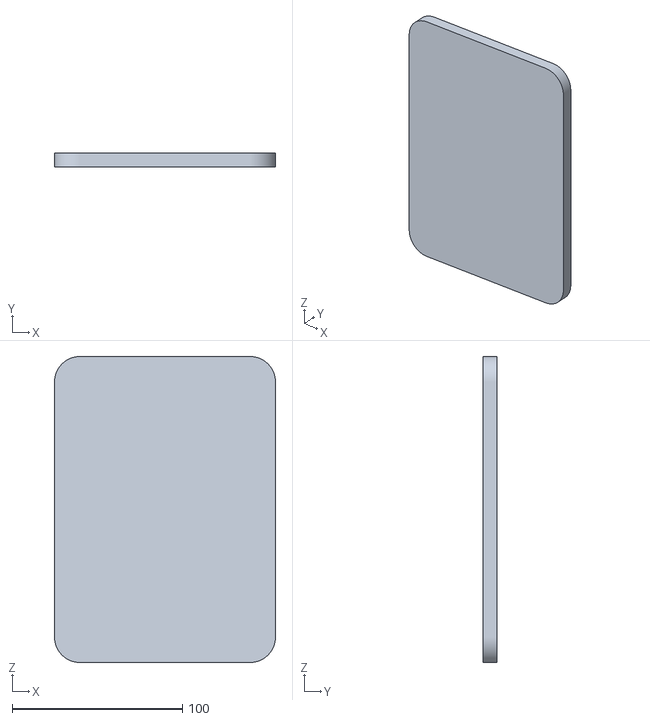
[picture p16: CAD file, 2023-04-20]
safata_1.stl
130.0 x 8.00 x 180.0

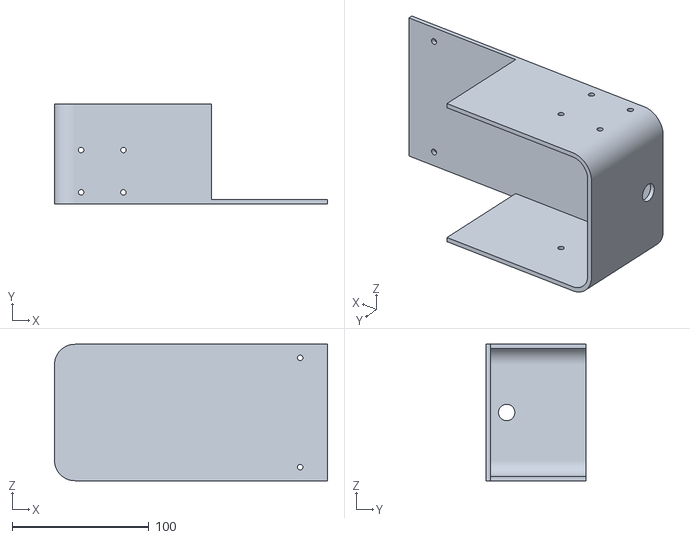
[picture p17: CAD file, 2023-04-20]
plataforma_central_1.stl
200.0 x 73.0 x 100.0

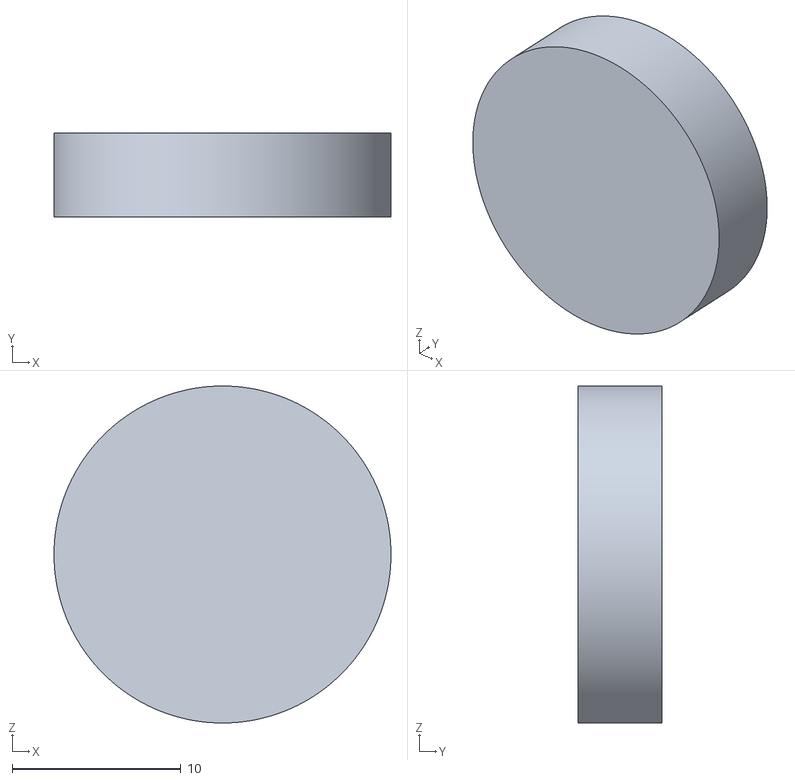
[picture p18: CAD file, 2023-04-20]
pilar_safata_4.stl
20.0 x 5.00 x 20.0

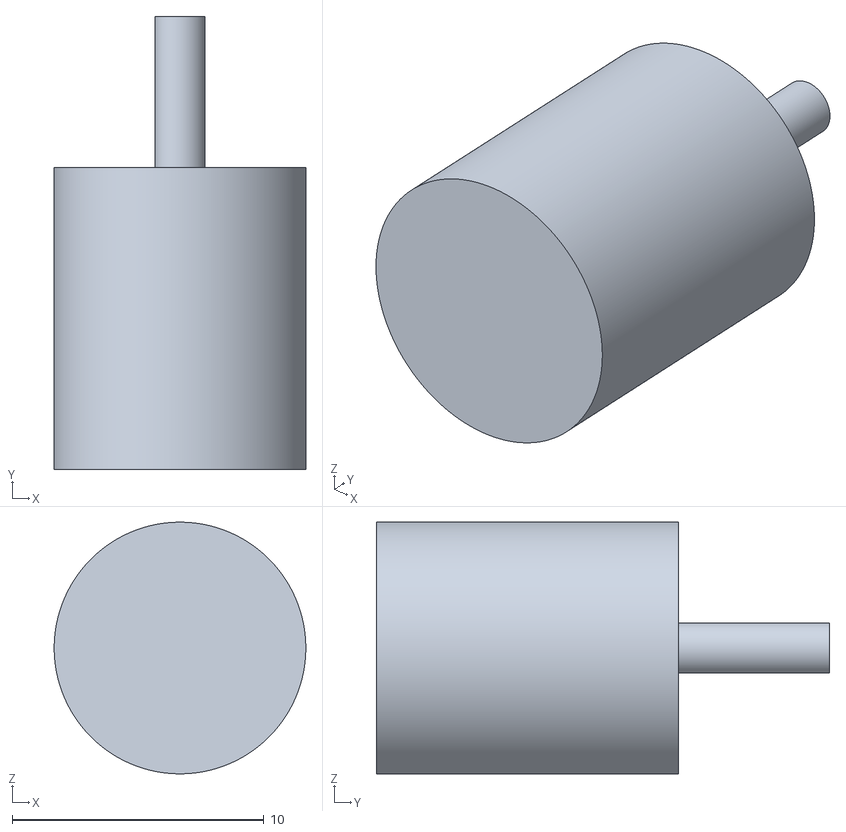
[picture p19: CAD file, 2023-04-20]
pilar_lidar_3.stl
10.0 x 18.0 x 10.00

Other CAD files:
plataforma_Rlateral_1.stl

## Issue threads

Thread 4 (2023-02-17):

Motor calculations

janabover, 2023-02-17:
Calculations of the motors to know the type of the motors to buy

EloiGarciaGisbert, 2023-02-28:
Motor Calculation

Since the chosen wheels had a radius of R=35 mm approximately, we can calculate the angular velocity (𝜔) at which the motor shaft should rotate.

v = w * R

Then we need to calculate the rpm of the wheels, the minimum and maximum to know the specifications of the motors:

In order to know the motor torque, we need to take in consideration the weight of the robot, the contact points touching the ground and  the friction of the surface.

Then we can calculate the total torque needed in order to start moving the robot from standstill in each wheel.

So each motor needs to have at least a torque of [0.105Nm · 4wheels / 2driven] = 0.210Nm.

From there now we can calculate the power which each wheel would need, although as there will be only 2 driven ones this total power will be distributed in those two.

So each motor needs to have at least a power of [1.5W · 4wheels / 2driven] = 3W.

Closed 2023-03-07.

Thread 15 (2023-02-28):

Meeting with microcontroler teacher

janabover, 2023-02-28:
In the meeting with the professor, the LIDAR technology was discussed, which is based on emitting a laser beam to measure the distance and shape of objects and surfaces in three dimensions. It was emphasized that this technology has a wide range of applications, such as mapping, object detection, autonomous navigation, and environmental monitoring.

The professor also explained that there are different types of LIDAR, which vary depending on the type of laser used and the frequency of measurement. The importance of spatial and temporal resolution in this technology was discussed and how this can affect applications.

Finally, the limitations of LIDAR were discussed, such as electromagnetic interference and difficulties in measuring transparent or reflective objects. It was concluded that, despite this, LIDAR technology is a very useful tool for a variety of applications and has great potential for the future.

Closed 2023-02-28.

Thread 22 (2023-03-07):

List of received material

moises-garin, 2023-03-07:
Material will be checked-out after returning it back.
Student **_MUST NOT_** edit/modify this list.

- [ ] 2 x motors PaP (provisional);
- [ ] 1 x mòdul ESP32;
- [ ] 2 x drivers motor DRV8825;
- [ ] 1 x ReguladorLM2596;
- [ ] 2 x Roda boja

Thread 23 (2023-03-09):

Programing Stepper's

JordiRF, 2023-03-09:
https://randomnerdtutorials.com/esp32-stepper-motor-28byj-48-uln2003/

JordiRF, 2023-03-09:
https://www.youtube.com/watch?v=v8GnBOLmrlg

JordiRF, 2023-03-09:
https://www.youtube.com/watch?v=09Mpkjcr0bo

JordiRF, 2023-03-09:
Controlling 2 DC Motors using ESP32 and L298N Motor driver

https://www.youtube.com/watch?v=2JTMqURJTwg

JordiRF, 2023-03-09:
Tutoria DRV8825 (stepper motor driver for esp32)

https://microcontrollerslab.com/drv8825-stepper-motor-driver-esp32-tutorial/

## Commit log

2023-04-20 3D printed files
    [pilar_lidar_3.stl, pilar_safata_4.stl, plataforma_Llateral_1.stl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]
2023-06-05 Add files via upload
    Arduino program for esp32
2023-06-05 Add files via upload
    Python program for LiDAR LD14
